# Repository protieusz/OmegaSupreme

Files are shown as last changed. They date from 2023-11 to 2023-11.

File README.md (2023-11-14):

# OmegaSupreme
RP2040 integrated components with integrated PMW3360 trackball sensor &amp; PER56 encoder. The OmegaSupreme is inspired by Ariamelon's Kiwano VIK module and jfedor2's RP2040 and PMW3660 module. The RP2040 pins are fully broken out into either pads or ribbon connections. Design this for convienience and easier to design a keyboard pcb around the OmegaSupreme itself.
Current on print by JLCPCB. Cost is a little bit on the pricey side. Around $89 CAD with shipping included. SK6812 mini e was omitted from the assembly to keep the cost down.  Part of the reason behind being pricey was the use of 3 extended parts i.e. 2 ribbon connectors and 1 JSH connector.  [Gerber](https://github.com/protieusz/OmegaSupreme/tree/main/OmegaSupremeRev4) files will be posted once I tested it. As always print at your "OWN RISK".  I do not offer support. You can feel free to modify it as long as you credit me. Thanks.

# Note: Currently there are 2 versions of Omega Supreme. OmegaSupreme USB C & Non USB C Version using a C3 Unified USB C Daughterboard card

# OmegaSupreme got mentioned on https://kbd.news/Starship-Bubu-OmegaSupreme-2184.html

# Update: Nov 13, 2023: OmegaSupreme USB Version.
Uploaded OmegaSupreme USB Version files. This is my preferred OmegaSupreme version. This version's production file will include a converted json file from EasyEDA to KiCad pcb file.  Please print and assembly at your own risk. I have the PCBs printed and tested so it works. No support will be given. Please follow the license when you modify, use, etc. Thanks.

# Extra BOMs:

1 [PMW3360 Sensor for trackball](https://www.aliexpress.com/item/1005005355003386.html?spm=a2g0o.order_list.order_list_main.23.31a51802RLpcrc)

2 [C3 Unified USB C Daughterboard card](https://42keebs.eu/shop/parts/unified-daughterboard-c3-c4/?attribute_version=C3)

3 [M3 3mm standoffs](https://www.aliexpress.com/item/1005004127890102.html?spm=a2g0o.order_list.order_list_main.60.31a51802RLpcrc)

4 [M3 8mm screw, buy 6mm just in case](https://www.aliexpress.com/item/1005003733948224.html?spm=a2g0o.order_list.order_list_main.41.31a51802RLpcrc)

5 [MJ311 or MJ310 steel or ceramic ball bearings for the trackball support holder unit. Steel is slightly noisy and scratchy compared to ceramic. Test it out on your own](https://www.aliexpress.com/item/1005005334424631.html?spm=a2g0o.order_list.order_list_main.66.31a51802RLpcrc)

6 [RGBs SK6812](https://www.aliexpress.com/item/1005003636607308.html?spm=a2g0o.order_list.order_list_main.5.31a51802RLpcrc)

7 [Reset & Boot switches](https://www.aliexpress.com/item/4001317902663.html?spm=a2g0o.order_list.order_list_main.240.31a51802RLpcrc)

# OmegaSupreme USB Version Final Pics:

Back Side


Front & Back Side


# Update: Nov 12, 2023. 
Currently there are 2 versions of Omega Supreme. The Rev 4 with all the extended connectors and a USB C version that does not require a USB C daughterboard card. I printed both versions and I find that Rev 1 is very annoying since it needs a USB C daughterboard card.  Nowadays, the reliability of PCBA and PCB printing from China factories are not that good if you are doing small 5 PCBs prototyping.  In my experience PCBA can be hit and miss.  Even the USB C daughterboard card can be a miss also.  So in order to eliminate headaches, I use the Omega Supreme USB C version where everything is in one place. Easier to diagnostic if shit goes south.

# REV 4 has 2 copper plated holes for the trackball support mount on the PCB which was missed during REV 1 print.  This PCB picture is REV1 without the corrected copper plated mount holes.









# D- and D+ pins are switched so when you attach your usb c daughterboard card, please be caution.



# REV 4 render. I don't have funds to print anymore.

Screenshot 2023-11-12 at 9 12 45 AM

Screenshot 2023-11-12 at 9 12 57 AM

# REV 1
Screenshot_2023-10-11_at_2 01 03_AM

Screenshot_2023-10-11_at_1 53 02_AM

# REV 3 Forgot to add M3 plated mounts for the trackball support and added RGB DOUT, 5v and GND for the last RGB on the OmegaSupreme

Screenshot 2023-10-12 at 11 52 33 AM
Screenshot 2023-10-12 at 11 53 11 AM

# License

</a></p>

You are free to:

Share — copy and redistribute the material in any medium or format

Adapt — remix, transform, and build upon the material

The licensor cannot revoke these freedoms as long as you follow the license terms.
Under the following terms:

Attribution — You must give appropriate credit, provide a link to the license, and indicate if changes were made. You may do so in any reasonable manner, but not in any way that suggests the licensor endorses you or your use.

NonCommercial — You may not use the material for commercial purposes.

ShareAlike — If you remix, transform, or build upon the material, you must distribute your contributions under the same license as the original.

No additional restrictions — You may not apply legal terms or technological measures that legally restrict others from doing anything the license permits.

OmegaSupreme by ProtieusKeebs is licensed under [CC BY-NC-SA 4.0](https://creativecommons.org/licenses/by-nc-sa/4.0/?ref=chooser-v1)

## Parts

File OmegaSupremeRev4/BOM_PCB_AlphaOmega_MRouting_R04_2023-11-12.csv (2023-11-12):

ID | Name | Designator | Footprint | Quantity | Manufacturer Part | Manufacturer | Supplier | Supplier Part | Price | link
1 | QWIIC HORIZONTAL JCSC | 1 | CONN-SMD_4P-P1.00_SM04B-SRSS-TB-LF-SN | 1 |  |  |  | C160404 | 0.178 | https://lcsc.com/product-detail/Wire-To-Board-Wire-To-Wire-Connector_JST-Sales-America_SM04B-SRSS-TB-LF-SN_JST-Sales-America-SM04B-SRSS-TB-LF-SN_C160404.html
2 | USB C | FPC1 | FPC-SMD_FH12-12S-0.5SH-55 | 1 | FH12-12S-0.5SH(55) | HRS(广濑) | LCSC | C88360 | 0.428 | https://lcsc.com/eda_search?q=C88360&%26type=1&ref=editor
3 | Header pins 1x04 1MM HOLES | H5 | 1X04 2.54MM HOLES HEADERS PINS 1MM HOLES | 1
4 | RP2040 | U4 | LQFN-56_L7.0-W7.0-P0.4-EP | 1 | RP2040 | Raspberry Pi(树莓派) | LCSC | C2040 | 1.076 | https://atta.szlcsc.com/upload/public/pdf/source/20210621/C2040_96F425825606B7957D87DD32E2512CA9.pdf
5 | PMW3360DM-T2QU | U7 | PMW3360DM-T2QU.PACK | 1 | PMW3360DM-T2QU |  |  |  |  | http://www.pixart.com/upload/PMS0058-PMW3360DM-T2QU-NNDS-R1.30-06042016_20160902201411.pdf
6 | 22pF | C3,C4 | C0402 | 2 | 0402CG220J500NT | FH(风华) | LCSC | C1555 | 0.001 | https://item.szlcsc.com/15869.html
7 | W25Q128JVSIQTR | U3 | SOIC-8_L5.3-W5.3-P1.27-LS8.0-BL | 1 | W25Q128JVSIQ | WINBOND(华邦) | LCSC | C97521 | 0.625 | https://item.szlcsc.com/63461.html
8 | 12MHz | X1 | OSC-SMD_4P-L3.2-W2.5-BL | 1 | X322512MSB4SI | YXC(扬兴晶振) | LCSC | C9002 | 0.059 | https://item.szlcsc.com/15866.html
9 | 1uF | C1,C2,C6,C9,C5 | C0402 | 5 | CL05A105KA5NQNC | SAMSUNG(三星) | LCSC | C52923 | 0.004 | https://item.szlcsc.com/15869.html
10 | 100nF | C15,C7,C10,C11,C12,C16,C13,C14 | C0402 | 8 | CL05B104KO5NNNC | SAMSUNG(三星) | LCSC | C1525 | 0.001 | https://item.szlcsc.com/15869.html
11 | RESET | U1 | RESET SWITCH | 1
12 | BOOT | U2 | RESET SWITCH | 1
13 | XC6206P332MR | U5 | SOT-23-3_L2.9-W1.6-P1.90-LS2.8-BR | 1 | XC6206P332MR | TOREX(特瑞仕) | LCSC | C5446 | 0.104 | https://item.szlcsc.com/14454.html
14 | SN74LVC1T45QDCKRQ1 | U6 | SC-70-6_L2.0-W1.3-P0.65-LS2.1-BR | 1 | SN74LVC1T45QDCKRQ1 | TI(德州仪器) | LCSC | C139353 | 0.264 | https://lcsc.com/eda_search?q=C139353&%26type=1&ref=editor
15 | 10uF | C8 | C0402 | 1 | CL05A106MQ5NUNC | SAMSUNG(三星) | LCSC | C15525 | 0.005 | https://item.szlcsc.com/15869.html
16 | AO Right | FPC2 | FPC-SMD_FH12-12S-0.5SH-55 | 1 | FH12-12S-0.5SH(55) | HRS(广濑) | LCSC | C88360 | 0.428 | https://lcsc.com/eda_search?q=C88360&%26type=1&ref=editor
17 | AO Left | FPC3 | FPC-SMD_FH12-12S-0.5SH-55 | 1 | FH12-12S-0.5SH(55) | HRS(广濑) | LCSC | C88360 | 0.428 | https://lcsc.com/eda_search?q=C88360&%26type=1&ref=editor
18 | SK6812MINI-E_C5149201 | U10,U12,U11 | LED-SMD_L3.2-W2.8-TR | 3 | SK6812MINI-E | 欧思科光电 | LCSC | C5149201 | 0.162 | https://lcsc.com/eda_search?q=C5149201&%26type=1&ref=editor
19 | 4.7uF | C17,C19,C20 | C0402 | 3 | CL05A475MP5NRNC | SAMSUNG(三星) | LCSC | C23733 | 0.006 | https://lcsc.com/eda_search?q=C23733&%26type=1&ref=editor
20 | 100nF | C18 | C0402 | 1 | CL05B104KB54PNC | SAMSUNG(三星) | LCSC | C307331 | 0.007 | https://lcsc.com/eda_search?q=C307331&%26type=1&ref=editor
21 | 10kΩ | R10,R12,R13 | R0402 | 3 | 0402WGF1002TCE | UNI-ROYAL(厚声) | LCSC | C25744 | 0.001 | https://lcsc.com/eda_search?q=C25744&%26type=1&ref=editor
22 | 39Ω | R11 | R0402 | 1 | 0402WGJ0390TCE | UNI-ROYAL(厚声) | LCSC | C25164 |  | https://lcsc.com/eda_search?q=C25164&%26type=1&ref=editor
23 | 15kΩ | R14 | R0402 | 1 | 0402WGF1502TCE | UNI-ROYAL(厚声) | LCSC | C25756 | 0.001 | https://lcsc.com/eda_search?q=C25756&%26type=1&ref=editor
24 | AP2127K-ADJTRG1 | U8 | SOT-23-5_L3.0-W1.7-P0.95-LS2.8-BR | 1 | AP2127K-ADJTRG1 | DIODES(美台) | LCSC | C96343 | 0.06 | https://lcsc.com/eda_search?q=C96343&%26type=1&ref=editor
25 | 5.1kΩ | R3,R4,R5 | R0402 | 3 | 0402WGF5101TCE | UNI-ROYAL(厚声) | LCSC | C25905 | 0.001 | https://item.szlcsc.com/323315.html
26 | 1kΩ | R6,R7 | R0402 | 2 | 0402WGF1001TCE | UNI-ROYAL(厚声) | LCSC | C11702 | 0.001 | https://item.szlcsc.com/323315.html
27 | 27Ω | R8,R9 | R0402 | 2 | 0402WGF270JTCE | UNI-ROYAL(厚声) | LCSC | C25100 | 0.001 | https://item.szlcsc.com/323315.html
28 | NO | 5VPOWER,GROUND,RGBDOUT,GND,GP12,GP6,GP13,GP14,GP15,5V,3V3 | PIN 1-PIN | 11
29 | MT_HOLE-3MM | U9,U13,U14,U15,U16,U17 | MT_HOLE-3MM | 6
30 | PER561-P115-N0015 | IC1 | PER561P115N0015 | 1

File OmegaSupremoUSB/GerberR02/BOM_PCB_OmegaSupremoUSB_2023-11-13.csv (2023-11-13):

ID | Name | Designator | Footprint | Quantity | Manufacturer Part | Manufacturer | Supplier | Supplier Part | Price | link
1 | PER561-P115-N0015 | IC1 | PER561P115N0015 | 1
2 | 5.1kΩ | R2,R3,R4,R5,R1 | R0402 | 5 | 0402WGF5101TCE | UNI-ROYAL(厚声) | LCSC | C25905 | 0.001 | https://item.szlcsc.com/323315.html
3 | TYPE-C-31-M-12 | USBC1 | USB-C_SMD-TYPE-C-31-M-12 | 1 | TYPE-C-31-M-12 | 韩国韩荣 | LCSC | C165948 | 0.165 | https://so.szlcsc.com/global.html?c=&k=C165948
4 | NO | 5V,GP6,GP12,GP13,GP14,GP15,+3V3,+5V,COL0,COL1,COL2,COL3,COL4,COL5,COL6,COL7,COL8,COL9,DOUT,ENCA,ENCB,GND1,GND2,GP25,GP26,GP27,GP29,RGBMCU,ROW0,ROW1,ROW2,ROW3 | PIN 1-PIN | 32
5 | 1uF | C1,C2,C5,C6,C9 | C0402 | 5 | CL05A105KA5NQNC | SAMSUNG(三星) | LCSC | C52923 | 0.004 | https://item.szlcsc.com/15869.html
6 | 22pF | C3,C4 | C0402 | 2 | 0402CG220J500NT | FH(风华) | LCSC | C1555 | 0.001 | https://item.szlcsc.com/15869.html
7 | 100nF | C7,C10,C11,C12,C13,C14,C15,C16 | C0402 | 8 | CL05B104KO5NNNC | SAMSUNG(三星) | LCSC | C1525 | 0.001 | https://item.szlcsc.com/15869.html
8 | 10uF | C8 | C0402 | 1 | CL05A106MQ5NUNC | SAMSUNG(三星) | LCSC | C15525 | 0.005 | https://item.szlcsc.com/15869.html
9 | 4.7uF | C17,C19,C20 | C0402 | 3 | CL05A475MP5NRNC | SAMSUNG(三星) | LCSC | C23733 | 0.006 | https://lcsc.com/eda_search?q=C23733&%26type=1&ref=editor
10 | 100nF | C18 | C0402 | 1 | CL05B104KB54PNC | SAMSUNG(三星) | LCSC | C307331 | 0.007 | https://lcsc.com/eda_search?q=C307331&%26type=1&ref=editor
11 | 1kΩ | R6,R7 | R0402 | 2 | 0402WGF1001TCE | UNI-ROYAL(厚声) | LCSC | C11702 | 0.001 | https://item.szlcsc.com/323315.html
12 | 27Ω | R8,R9 | R0402 | 2 | 0402WGF270JTCE | UNI-ROYAL(厚声) | LCSC | C25100 | 0.001 | https://item.szlcsc.com/323315.html
13 | 10kΩ | R10,R12,R13 | R0402 | 3 | 0402WGF1002TCE | UNI-ROYAL(厚声) | LCSC | C25744 | 0.001 | https://lcsc.com/eda_search?q=C25744&%26type=1&ref=editor
14 | 39Ω | R11 | R0402 | 1 | 0402WGJ0390TCE | UNI-ROYAL(厚声) | LCSC | C25164 |  | https://lcsc.com/eda_search?q=C25164&%26type=1&ref=editor
15 | 15kΩ | R14 | R0402 | 1 | 0402WGF1502TCE | UNI-ROYAL(厚声) | LCSC | C25756 | 0.001 | https://lcsc.com/eda_search?q=C25756&%26type=1&ref=editor
16 | RESET | U1 | RESET SWITCH | 1
17 | BOOT | U2 | RESET SWITCH | 1
18 | W25Q128JVSIQTR | U3 | SOIC-8_L5.3-W5.3-P1.27-LS8.0-BL | 1 | W25Q128JVSIQ | WINBOND(华邦) | LCSC | C97521 | 0.625 | https://item.szlcsc.com/63461.html
19 | RP2040 | U4 | LQFN-56_L7.0-W7.0-P0.4-EP | 1 | RP2040 | Raspberry Pi(树莓派) | LCSC | C2040 | 1.076 | https://atta.szlcsc.com/upload/public/pdf/source/20210621/C2040_96F425825606B7957D87DD32E2512CA9.pdf
20 | XC6206P332MR | U5 | SOT-23-3_L2.9-W1.6-P1.90-LS2.8-BR | 1 | XC6206P332MR | TOREX(特瑞仕) | LCSC | C5446 | 0.104 | https://item.szlcsc.com/14454.html
21 | SN74LVC1T45QDCKRQ1 | U6 | SC-70-6_L2.0-W1.3-P0.65-LS2.1-BR | 1 | SN74LVC1T45QDCKRQ1 | TI(德州仪器) | LCSC | C139353 | 0.264 | https://lcsc.com/eda_search?q=C139353&%26type=1&ref=editor
22 | PMW3360DM-T2QU | U7 | PMW3360DM-T2QU.PACK | 1 | PMW3360DM-T2QU |  |  |  |  | http://www.pixart.com/upload/PMS0058-PMW3360DM-T2QU-NNDS-R1.30-06042016_20160902201411.pdf
23 | AP2127K-ADJTRG1 | U8 | SOT-23-5_L3.0-W1.7-P0.95-LS2.8-BR | 1 | AP2127K-ADJTRG1 | DIODES(美台) | LCSC | C96343 | 0.06 | https://lcsc.com/eda_search?q=C96343&%26type=1&ref=editor
24 | NO | U9,U13,U14,U15,U16,U17 | MT_HOLE-3MM | 6
25 | SK6812MINI-E_C5149201 | U10,U11,U12 | LED-SMD_L3.2-W2.8-TR | 3 | SK6812MINI-E | 欧思科光电 | LCSC | C5149201 | 0.162 | https://lcsc.com/eda_search?q=C5149201&%26type=1&ref=editor
26 | 12MHz | X1 | OSC-SMD_4P-L3.2-W2.5-BL | 1 | X322512MSB4SI | YXC(扬兴晶振) | LCSC | C9002 | 0.059 | https://item.szlcsc.com/15866.html
27 | PRTR5V0U2X,215 | D11 | SOT-143_L2.9-W1.3-P1.92-LS2.3-BR | 1 | PRTR5V0U2X,215 | Nexperia(安世) | LCSC | C12333 | 0.158 | https://item.szlcsc.com/280548.html
28 | BSMD0805-020-15V | F1 | F0805 | 1 | BSMD0805-020-15V | BHFUSE(佰宏) | LCSC | C883103 | 0.045 | https://item.szlcsc.com/343298.html

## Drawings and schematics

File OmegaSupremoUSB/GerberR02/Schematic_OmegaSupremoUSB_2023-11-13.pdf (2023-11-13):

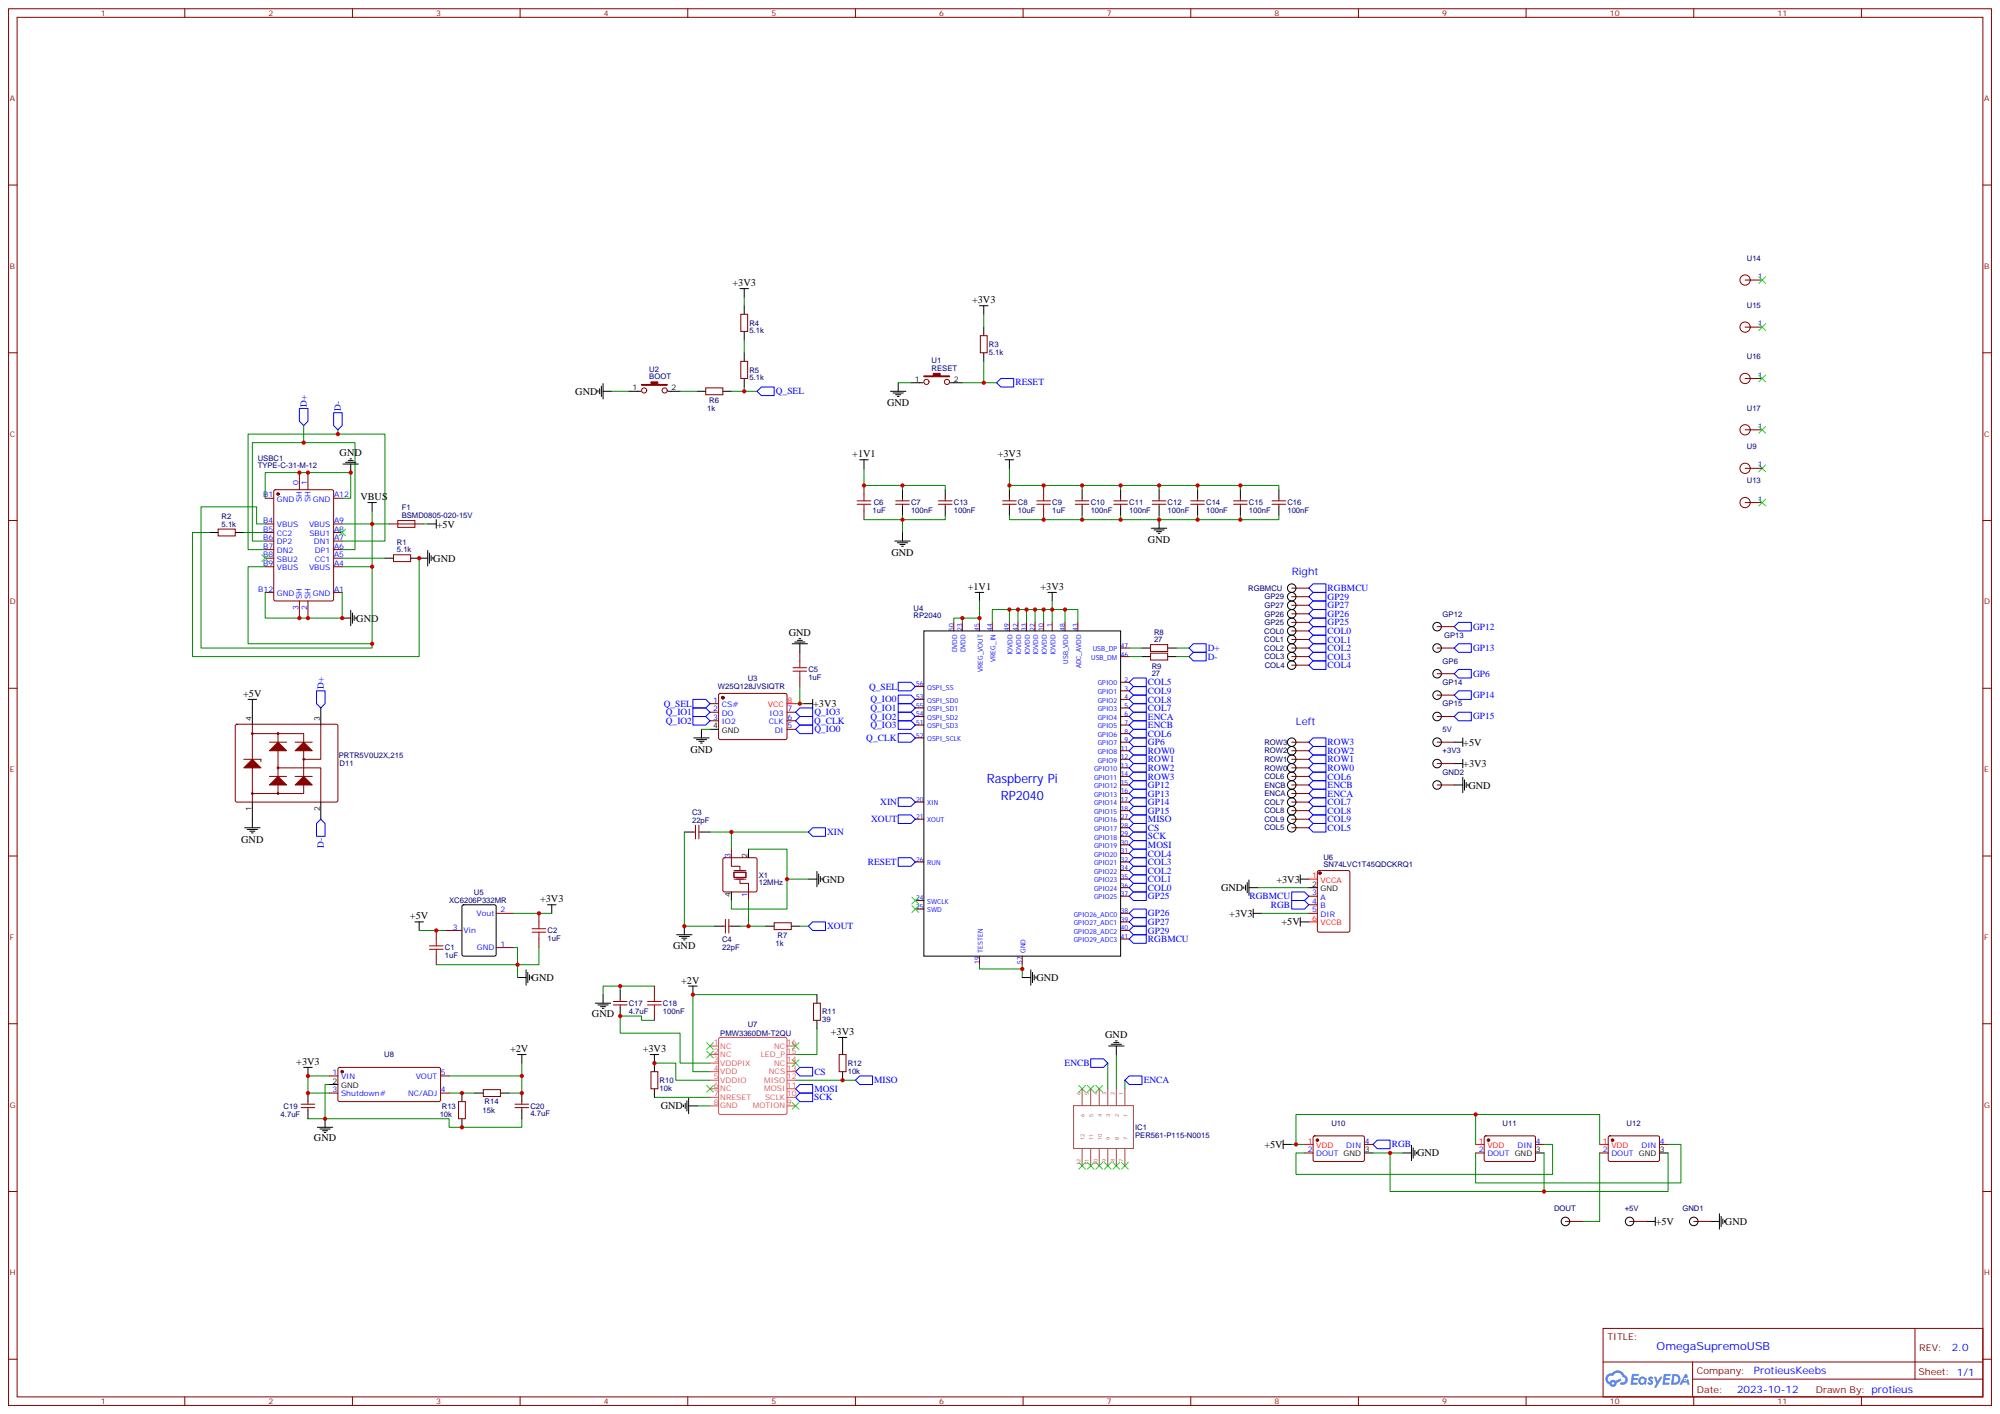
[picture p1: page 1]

SCLK 10 MOSI 11 MISO 12 NCS 13 NC 14 LED_P 15 NC 16

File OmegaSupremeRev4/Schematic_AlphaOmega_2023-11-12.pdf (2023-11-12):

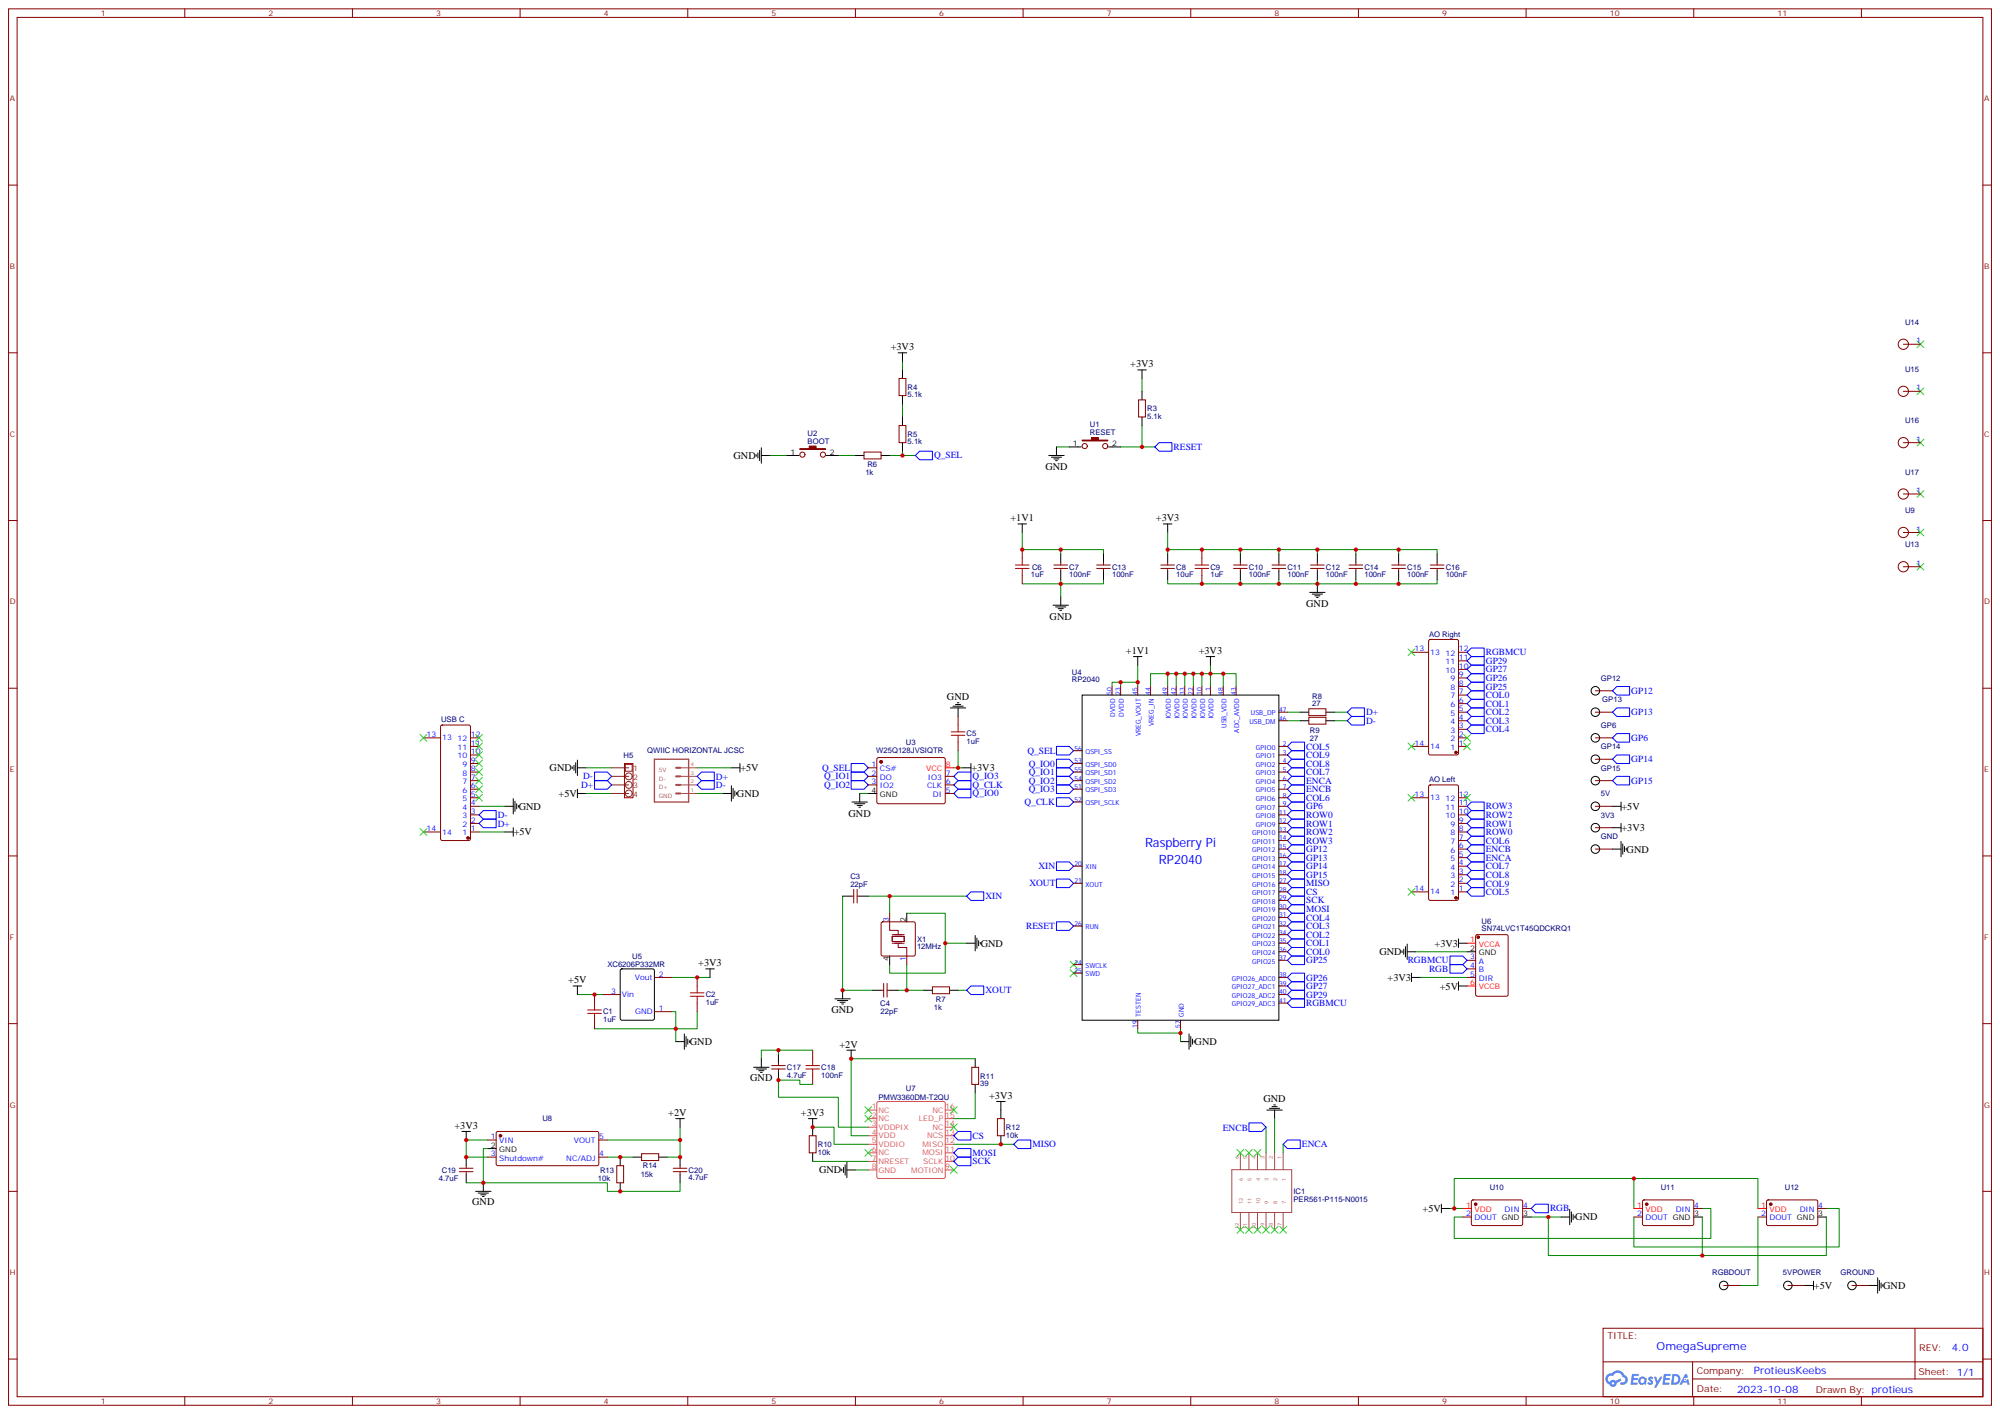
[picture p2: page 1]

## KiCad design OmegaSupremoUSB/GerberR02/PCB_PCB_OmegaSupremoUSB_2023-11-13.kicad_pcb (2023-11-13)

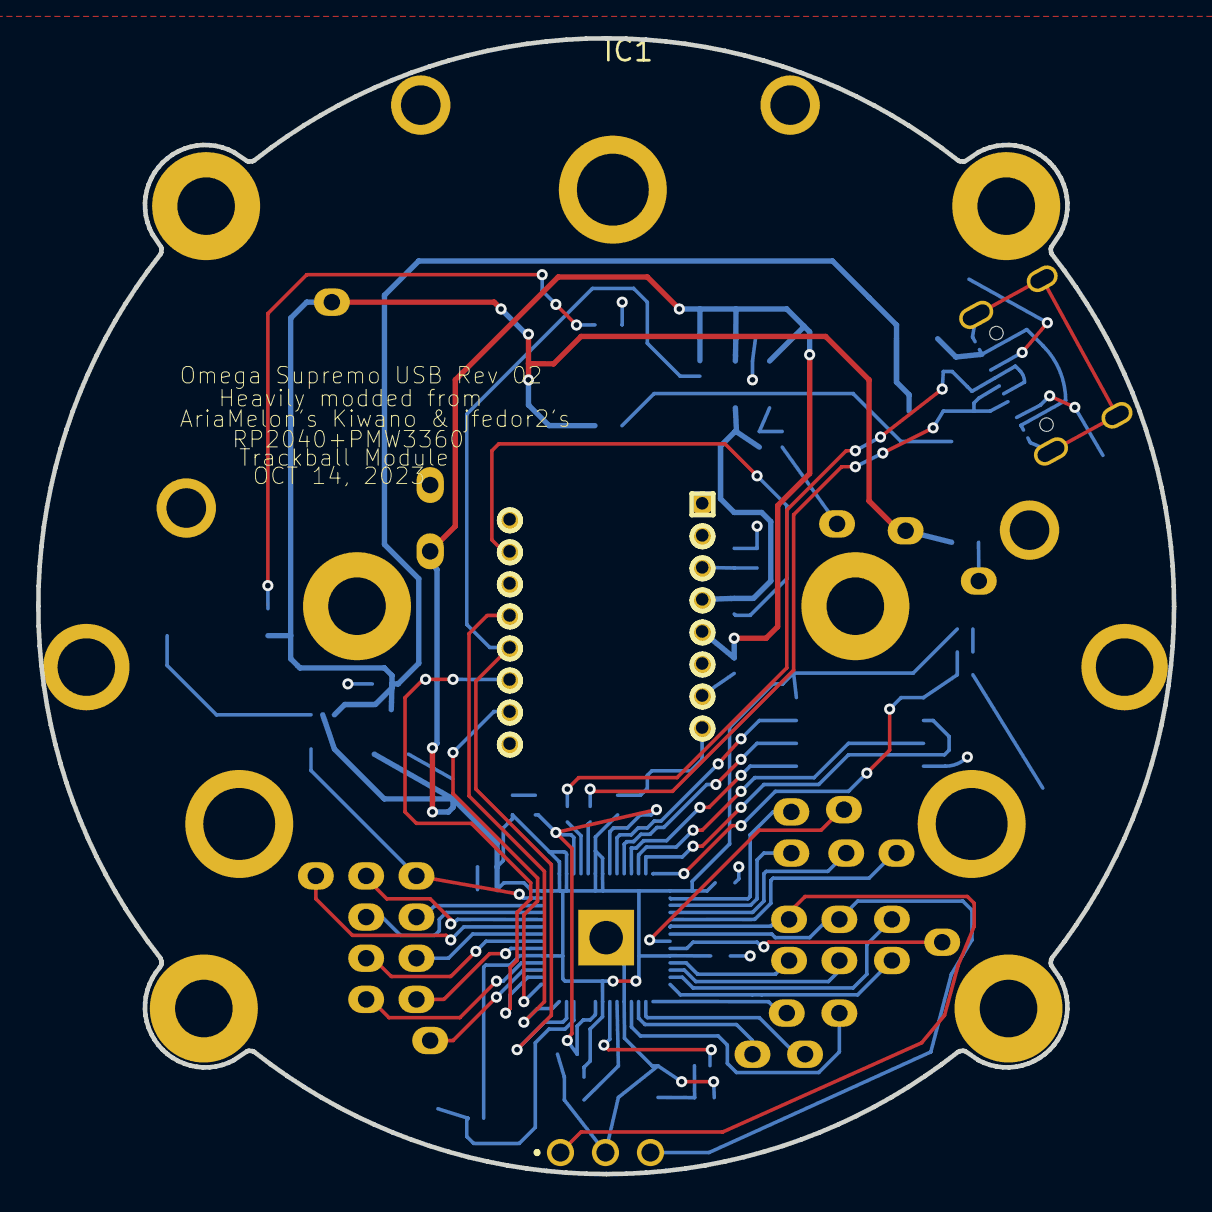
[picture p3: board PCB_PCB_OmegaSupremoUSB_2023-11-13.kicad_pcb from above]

Board: 2 copper layers, 63.1 x 63.1 mm, 88 parts (0 on the bottom side), 62 nets.

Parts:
5V: NO; PIN 1-PIN
+3V3, +5V: NO; PIN 1-PIN
C1, C2, C5, C6, C9: 1uF; C0402
C3, C4: 22pF; C0402
C7, C10, C11, C12, C13, C14, C15, C16, C18: 100nF; C0402
C8: 10uF; C0402
C17, C19, C20: 4.7uF; C0402
COL0, COL1, COL2, COL3, COL4, COL5, COL6, COL7, COL8, COL9: NO; PIN 1-PIN
D11: PRTR5V0U2X,215; SOT-143_L2.9-W1.3-P1.92-LS2.3-BR
DOUT: NO; PIN 1-PIN
ENCA: NO; PIN 1-PIN
ENCB: NO; PIN 1-PIN
F1: BSMD0805-020-15V; F0805
GND1, GND2: NO; PIN 1-PIN
GP6, GP12, GP13, GP14, GP15, GP25, GP26, GP27, GP29: NO; PIN 1-PIN
IC1: PER561-P115-N0015; PER561P115N0015
R1, R2, R3, R4, R5: 5.1kΩ; R0402
R6, R7: 1kΩ; R0402
R8, R9: 27Ω; R0402
R10, R12, R13: 10kΩ; R0402
R11: 39Ω; R0402
R14: 15kΩ; R0402
RGBMCU: NO; PIN 1-PIN
ROW0, ROW1, ROW2, ROW3: NO; PIN 1-PIN
U1: RESET; RESET SWITCH
U2: BOOT; RESET SWITCH
U3: W25Q128JVSIQTR; SOIC-8_L5.3-W5.3-P1.27-LS8.0-BL
U4: RP2040; LQFN-56_L7.0-W7.0-P0.4-EP
U5: XC6206P332MR; SOT-23-3_L2.9-W1.6-P1.90-LS2.8-BR
U6: SN74LVC1T45QDCKRQ1; SC-70-6_L2.0-W1.3-P0.65-LS2.1-BR
U7: PMW3360DM-T2QU; PMW3360DM-T2QU.PACK
U8: AP2127K-ADJTRG1; SOT-23-5_L3.0-W1.7-P0.95-LS2.8-BR
U9, U13, U14, U15, U16, U17: NO; MT_HOLE-3MM
U10, U11, U12: SK6812MINI-E_C5149201; LED-SMD_L3.2-W2.8-TR
USBC1: TYPE-C-31-M-12; USB-C_SMD-TYPE-C-31-M-12
X1: 12MHz; OSC-SMD_4P-L3.2-W2.5-BL

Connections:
+1V1: C6.2, C7.2, C13.2, U4.23, U4.45, U4.50
+2V: C20.2, R11.2, R14.2, U7.4, U8.5
+3V3: +3V3.1, C2.2, C5.2, C8.2, C9.2, C10.2, C11.2, C12.2, C14.2, C15.2, C16.2, C19.2, R3.2, R4.2, R10.2, R12.2, U3.8, U4.1, U4.10, U4.22, U4.33, U4.42, U4.43, U4.44, U4.48, U4.49, U5.2, U6.1, U6.5, U7.5, U8.1, U8.3
+5V: 5V.1, +5V.1, C1.2, D11.4, F1.2, U5.3, U6.6, U10.1, U11.1, U12.1
C4_1: C4.1, R7.1, X1.1
C18_1: C17.1, C18.1, U7.3
COL0: COL0.1, U4.36
COL1: COL1.1, U4.35
COL2: COL2.1, U4.34
COL3: COL3.1, U4.32
COL4: COL4.1, U4.31
COL5: COL5.1, U4.2
COL6: COL6.1, U4.8
COL7: COL7.1, U4.5
COL8: COL8.1, U4.4
COL9: COL9.1, U4.3
CS: U4.28, U7.13
D+: D11.3, R8.2, USBC1.A6, USBC1.B6
D-: D11.2, R9.2, USBC1.A7, USBC1.B7
DOUT_1: DOUT.1, U12.2
ENCA: ENCA.1, IC1.1, U4.6
ENCB: ENCB.1, IC1.3, U4.7
GND: C1.1, C2.1, C3.1, C4.2, C5.1, C6.1, C7.1, C8.1, C9.1, C10.1, C11.1, C12.1, C13.1, C14.1, C15.1, C16.1, C17.2, C18.2, C19.1, C20.1, D11.1, GND1.1, GND2.1, IC1.2, R1.2, R2.1, R13.1, U1.1, U2.1, U3.4, U4.19, U4.57, U5.1, U6.2, U7.8, U8.2, U10.3, U11.3, U12.3, USBC1.0, USBC1.1, USBC1.2, USBC1.3, USBC1.A1, USBC1.A12, USBC1.B1, USBC1.B12, X1.2, X1.4
GP6: GP6.1, U4.9
GP12: GP12.1, U4.15
GP13: GP13.1, U4.16
GP14: GP14.1, U4.17
GP15: GP15.1, U4.18
GP25: GP25.1, U4.37
GP26: GP26.1, U4.38
GP27: GP27.1, U4.39
GP29: GP29.1, U4.40
MISO: R12.1, U4.27, U7.12
MOSI: U4.30, U7.11
Q_CLK: U3.6, U4.52
Q_IO0: U3.5, U4.53
Q_IO1: U3.2, U4.55
Q_IO2: U3.3, U4.54
Q_IO3: U3.7, U4.51
Q_SEL: R5.1, R6.2, U3.1, U4.56
R5_2: R4.1, R5.2
R10_1: R10.1, U7.7
R11_1: R11.1, U7.15
R14_1: R13.2, R14.1, U8.4
RESET: R3.1, U1.2, U4.26
RGB: U6.4, U10.4
RGBMCU: RGBMCU.1, U4.41, U6.3
ROW0: ROW0.1, U4.11
ROW1: ROW1.1, U4.12
ROW2: ROW2.1, U4.13
ROW3: ROW3.1, U4.14
SCK: U4.29, U7.10
U2_2: R6.1, U2.2
U4_46: R9.1, U4.46
U4_47: R8.1, U4.47
U10_2: U10.2, U11.4
U11_2: U11.2, U12.4
USBC1_A5: R1.1, USBC1.A5
USBC1_B5: R2.2, USBC1.B5
VBUS: F1.1, USBC1.A4, USBC1.A9, USBC1.B4, USBC1.B9
XIN: C3.2, U4.20, X1.3
XOUT: R7.2, U4.21

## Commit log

2023-11-12 Latest Revision that has the fixed mounting screws
    [BOM_PCB_AlphaOmega_MRouting_R04_2023-11-12.csv, PickAndPlace_PCB_AlphaOmega_MRouting_R04_2023-11-12.csv]
2023-11-12 Updated to REV 3
    [BOM_PCB_AlphaOmega_MRouting_R04_2023-11-12.csv, PickAndPlace_PCB_AlphaOmega_MRouting_R04_2023-11-12.csv]
2023-11-13 OmegaSupreme USB Production Files
    [BOM_PCB_OmegaSupremoUSB_2023-11-13.csv, PCB_PCB_OmegaSupremoUSB_2023-11-13.kicad_pcb, PickAndPlace_PCB_OmegaSupremoUSB_2023-11-13.csv]

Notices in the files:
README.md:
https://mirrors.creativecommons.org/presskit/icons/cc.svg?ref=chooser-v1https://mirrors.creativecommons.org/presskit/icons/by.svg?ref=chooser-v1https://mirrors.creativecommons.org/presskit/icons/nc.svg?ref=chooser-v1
